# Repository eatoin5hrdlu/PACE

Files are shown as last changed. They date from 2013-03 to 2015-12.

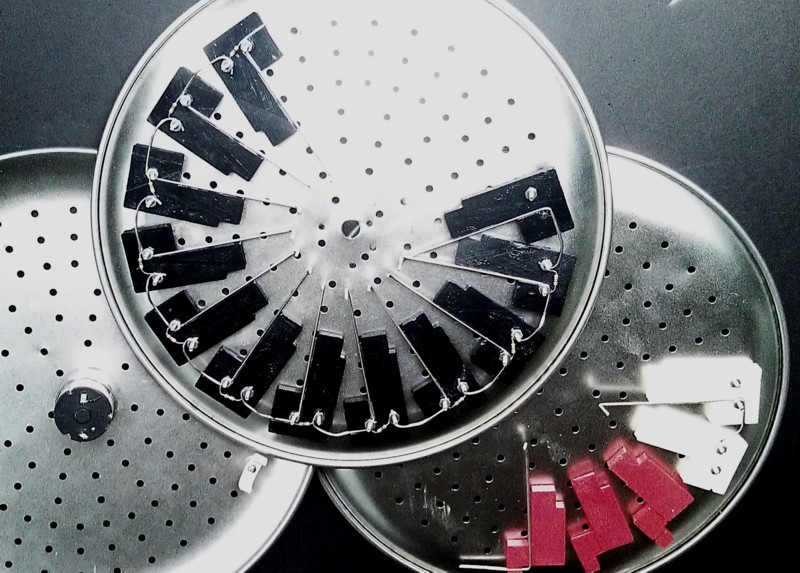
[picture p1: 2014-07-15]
CAD/assembly.jpg

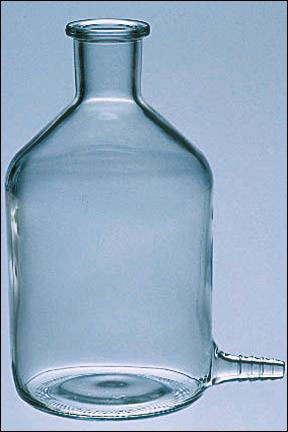
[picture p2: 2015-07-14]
Doc/F7747-01-wl.jpg

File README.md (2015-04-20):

EvoStat:  A PhageStat to support PACE and PATHE Experiments
NB: in the process of namechange from PACE to EvoStat. PACE github repository will disappear EvoStat will appear.
====
Software and Hardware for a low-cost platform for PACE and PATHE experiments.

PATHE (Phage-Assisted Three-Hybrid Evolution) is an enhancement to PACE (Phage Assisted Continuous Evolution) described by Kevin M. Esvelt, Jacob C. Carlson, and David R. Liu in http://www.ncbi.nlm.nih.gov/pubmed/21478873

This project contains Arduino code for a CellStat(Turbidostat), Sample Collector, and Lagoons
as well as the server software to provide an on-screen interface to Temperature, Turbidity, Flowrate,
and Sample Collector control and Web interface.

SWI-Prolog based web server, GUI, and Turbidostat control software
is written mostly in Prolog/Xpce with some Python (e.g. pySerial, for a 
portable serial interface to Arduino) and HTML. Bluetooth interface added as foreign function library to SWI-Prolog currently eliminates the need for pySerial. See github.com/eatoin5hrdlu/plblue 

Running EvoStat on a Linux or Windows machine provides an interface for multiple phageStats with using Bluetooth connected Arduino running host.ino for the Host Cellstat, multiple Bluetooth connected Arduinos for Lagoons (lagoon.ino), and a sample collector: Bluetooth connected Arduino running collector.ino. (Using a WiFi camera and bluetooth modules has reduced apparatus wiring by 90%)

It also contains a web server to provide essentially the same
interface via the URL:  

    http://&lt;machine-name&gt;:8080/evostat.pl    

Prerequisite Software
====
- Python2.7
- OpenCV (plus: "apt-get install python-opencv")
- SWI-Prolog with Xpce
- Arduino IDE (Processing)

Getting Started
====
Clone the repo:

    git clone https://github.com/eatoin5hrdlu/EvoStat.git

Run the app:

    cd app
    python levelapp.py

Using the controls, line up the lagoons and turbidostat in the camera frame
with the corresponding lines being  (blob detection being added to automate this)

Controls
====
* z  - read one frame and find levels and display
* r - read, find levels and display for 20 seconds.
* 0<nl>   Select the turbidostat as current vessel
* {1,2,3,4 for lagoons)
* <arrow keys> to move up/down/left/right, or:
* h  - move to the left
* j  - move down
* k  - move up
* l  - move right
* t -make region taller
* s - make region shorter
* f - make region fatter
* d - diminish (make region thinner)
* x - exits the program

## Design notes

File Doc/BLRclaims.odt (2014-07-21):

Title: A Laboratory Apparatus for Macromolecular and Biological Evolution

Inventor: Peter Reintjes

References:

Selection and Evolution of Bacteriophages in Cellstat, Yuruzu Husimi, Advances in Biophysics, Vol. 25, pp.1-43 (1989).

A system for the continuous directed evolution of biomolecules,Esvelt KM (http://www.ncbi.nlm.nih.gov/pubmed?term=Esvelt%20KM%5BAuthor%5D&cauthor=true&cauthor_uid=21478873)1, Carlson JC (http://www.ncbi.nlm.nih.gov/pubmed?term=Carlson%20JC%5BAuthor%5D&cauthor=true&cauthor_uid=21478873), Liu DR (http://www.ncbi.nlm.nih.gov/pubmed?term=Liu%20DR%5BAuthor%5D&cauthor=true&cauthor_uid=21478873), Nature. (http://www.ncbi.nlm.nih.gov/pubmed/21478873#) 2011 Apr 28;472(7344):499-503. doi: 10.1038/nature09929. Epub 2011 Apr 10.

pH Indicator, Wikipedia, http://en.wikipedia.org/wiki/PH_indicator

Background of the invention:

Macromolecular engineering can employ the mechanisms of evolution: mutation and selection, to construct novel genetic sequences with desired properties. Earlier means consisted of separate steps for mutation, selection, and cloning, with one or more manual steps, limiting the number of complete cycles to a few per day. Recent advances use continuous cell cultivation techniques, such as a cellstat, to create an environment for continuous evolution. One such method employs the evolution of a bacterial virus with a generation time on the order of a few minutes. A requirement for the application of these mechanisms is the relatively long-term maintenance of environmental conditions required by the organisms or macromolecules involved. Just as the simplest device to control a heating or cooling device from the feedback provided by a temperature sensor is called a thermostat, devices for controlling chemical concentrations, cell concentrations, and active bacterial virus populations are given the names chemostat, turbidostat, and phagestat. In each case, particular measurements correlated with the condition being maintained must be sensed to provide feedback for the control of temperature, nutrient concentration, flow rate, or other condition.

Sensors for some properties such as temperature, pH, reageant concentration may require contact with the materials involved and in the case of biological systems, this can require the devices to withstand an autoclaving procedure involving elevated temperature and pressures. In addition, such devices must withstand the potentially corrosive effects of the biological environment which can have chemistry similar to ocean water. For these reasons, we would prefer to use non-contact means (e.g optical) to measure environmental conditions.

Multiple light sources can be used with a single camera to detect the reflected color, degree of light scattering, and light absorption at various wavelengths. With the addition of chemical indicators such as pH indicators can allow the optical means to measure acidity and the addition of a sensitive infra-red detector to register accurate temperature measurements.

Substantial aeration may be necessary to achieve maximum growth rate of the host cell culture which can increase the acidity of the solution by the addition of dissolved carbon dioxide thereby requiring a means of controlling said acidity.

Summary of the invention:

A system of non-contact sensing means and computer activated controls to maintain multiple environmental conditions including, but not limited to, temperature, turbidity as a proxy for cell density, liquid levels, reflected or transmitted spectra as proxies for chemical concentrations and pH, biolumenescence as a proxy for phage population and macromolecule concentration.

Although mutation rates can be elevated and the selection process accelerated to the life-cycle of bacterial phage of only a few minutes, evolution experiments may still require days, weeks, or even longer to achieve the desired results. The present invention has increased reliability through the reduction of moving or wearing parts.

Precise pH stability is achieved by adding one or more non-toxic pH indicators to the nutrient stock which give a suitable color transition at the desired pH setting. A combination of reflected and absorbed spectral information can be used to gain precision.

A system necessary to maintain a stable population of bacterial phage (the evolving species), requires a cellstat subsystem to maintain the uninfected host cell production, which in turn requires turbidostat and thermostatic controls.

An indicator may be used to obtain quite precise measurements of pH by measuring absorbance at two or more wavelengths. The principle can be illustrated by taking the indicator to be a simple acid, HA, which dissociates into H+ and A-. HA is in equilibrium with H+ + A-

The value of the acid dissociation constant, pKa, must be known. The molar absorbances, εHA and εA- of the two species HA and A- at wavelengths λx and λy must also have been determined by previous experiment. Assuming that Beer's law is obeyed, the measured absorbances Ax and Ay at the two wavelengths are simply the sum of the absorbances due to each species.

A_x = [HA]\epsilon^x_{HA} + [A^-]\epsilon^x_{A^-}

A_y = [HA]\epsilon^y_{HA} + [A^-]\epsilon^y_{A^-}

These are two equation in the two concentrations [HA] and [A-]. Once solved, the pH is obtained as

\textrm{pH} = \textrm{pK}_{a}+ \log \frac{[\textrm{A}^-]}{[\textrm{HA}]}

If measurements are made at more than two wavelengths the concentrations [HA] and [A-] can be calculated by linear least squares. In fact a whole spectrum may be used for this purpose. The process is illustrated for the indicator bromocresol green. The observed spectrum (green) is the sum of the spectra of HA (gold) and of A- (blue), weighted for the concentration of the two species.

When a single indicator is used this method is limited to measurements in the pH range pKa ± 1, but this range can be extended by using mixtures of two or more indicators. Because indicators have intense absorption spectra the indicator concentration is relatively low so that it can usually be assumed that the indicator itself has negligible effect on pH.

Description of the drawings:

Drawing 1: Liquid flow path

1. Nutrient supply line
2. Nutrient supply pump
3. Nutrient supply valve
4. Host cell supply line
5. Host cell supply pump
6. Host cell supply valve
7. One-to-four line splitter for host cell supply
8. Host cell supply line for lagoon 1 (one of four)
9. Compression rod valve for Host cell supply for lagoon 1
10. Host cell supply canulla for lagoon 1
11. Inducer supply line
12. Inducer supply pump
13. Inducer supply valve
14. One-to-four line splitter for inducer
15. Inducer supply line for lagoon 1 (one of four)
16. Compression rod valve for inducer supply for lagoon 1
17. Inducer supply canulla for lagoon 1
18. Outflow canulla for lagoon 1 (one of four)
19. Compression rod valve for lagoon 1 outflow
20. Four-to-one line combiner
21. Outflow valve
22. Outflow pump

Drawing 2: Lighting and Image capture

1. Meniscus highlight LED for host cell incubator
2. Meniscus highlight LED for lagoon 1 (one of four)
3. LED Laser
4. Full spectrum LED
5. Camera

Chemostat

Turbidostat

Cellstat

Phagestat

Description of the invention:

A source of liquid nutrient sufficient to maintain the maximum flow rate through the system, a multiplicity of supplementary liquid reagents (inducers) which may be added to the containers.

A pump and valve complex, the primer, which can prime (valve closed, pump on) and then maintain (valve open, pump off) sufficient flow to sustain the maximum flow rate required by the system.

A flow control apparatus consisting of a multiplicity of valves controlling the flow of liquid between the outflow and inflow of the host cell container and each of the lagoons.

A host cell container which is elevated with respect to the phagestat containers (lagoons).

A multiplicity of secondary containers (lagoons) containing a population of bacteria and bacterial phage, each of said lagoons having one or more inputs from and one or more outputs to the flow-control apparatus.

A non-contact (IR) temperature sensor, camera, computer, and image processing software to provide real-time information about the level, turbidity, reflected color, spectral absorbance, and luminescence of the liquid in each of the transparent containers.

Means to control lighting in the form of yellow light projected up from beneath the transparent containers to illuminate the meniscus of the liquid in the container, a laser projecting into the transparent host cell container from the side, and a full spectrum light from the direction of the camera to provide visual monitoring of the apparatus.

A liquid sensing device in the bottom of the apparatus to detect leaks and a means to react to said leaks by shutting off the flow of liquid and a means for reporting the condition of the apparatus.

Claims:

Claim 1: Simultaneous liquid level detection for multiple transparent containers.

Consisting of an edge detection algorithm from the set {Marr-Hidreth, Roberts cross (http://homepages.inf.ed.ac.uk/rbf/HIPR2/roberts.htm), Sobel (http://homepages.inf.ed.ac.uk/rbf/HIPR2/sobel.htm), Compass (http://homepages.inf.ed.ac.uk/rbf/HIPR2/prewitt.htm), Canny (http://homepages.inf.ed.ac.uk/rbf/HIPR2/canny.htm)} followed by a line detection algorithm from the set {Hough, Convolution, (http://homepages.inf.ed.ac.uk/rbf/HIPR2/linedet.htm) Radon (http://en.wikipedia.org/wiki/Radon_transform) , Cauchy-Crofton (http://en.wikipedia.org/wiki/Crofton_formula) , Fourier (http://en.wikipedia.org/wiki/Fourier_transform) } to detect the illuminated meniscus of the liquid in said transparent containers.

Claim 2: Claim 1 where the transparent containers are illuminated from below.

Claim 3: Flow modulation consisting of multiple valves controlling a multiplicity of inputs and a single output for a multiplicity of containers where the amount of time alloted to opening each valve is varied to modulate the rate of flow through each valve.

Claim 4: The apparatus of claim 3 where the flow modulation for each container is a function of the instantaneous, time-derivative, and/or time-integral of the said containers liquid level.

Claim 5: The apparatus of claim 4 where the flow control parameters are computed by a calibration process consisting of:

1. An output leakage measurement taken by closing all input flow channels and measuring the rate of output flow with all output valves closed..
2. A nominal output flow measurement taken by closing all input flow channels and measuring the rate of output flow with each output valve opened for a specific interval.
3. An input leakage measurement consisting of closing of all output flow channels and measuring the rate of input flow with input valves closed.
4. A nominal input flow measurement taken by clsing all output flow channels and measuring the rate of input flow with each input valve opened for a specific interval.

Claim 6: The apparatus of claim 5 where the individual liquid containers are transparent and the rate of flow is measured by the image processing means of line detection.

Claim 7: The apparatus of claim 5 where the rate of flow is measured by detecting any or all of the instantaneous, time-derivative, and/or time-derivative liquid levels of the containers.

Claim 8: The apparatus of claim 5 where one or more pH indicators are added to the containers and a pH value is computed from the absorbence of wavelengths from one or more of the light sources.<

Keywords: multiple-valve, image processing, line detection, controlled illumination, turbidity.

Multi-valve control for liquid flow control of multiple

A Laboratory Apparatus for Macromolecular and Biological Evolution

10 Digital Outputs:

Laser

Yellow light

White light

Nutrient pump

Host cell pump and valve

Inducer pump and valve

Lagoon outflow pump and valve

1 PWM output: Valve pointer

1 Analog input

A system for controlling multiple turbidostats and cellstats with minimal medium contact.

Consisting of a dark environmental chamber with an optical (PIR, IR) temperature sensor, a heat source, a multiplicity of light sources under computer control, a digital camera connected to said computer, a multiplicity of liquid pumps, each with a valve whose input and output are in parallel with the pump input and output, an air pump, and stirring means in each of the containers.

A multiplicity of valves each consisting of a stiff rod compressing a soft tube in which the nutrient, cell culture, inducer, or other liquid would otherwise flow freely. A central pointer with adjustable torque which contacts said rods sequentially and flexes it sufficiently to relieve the compression on said tube allowing the liquid to flow freely for a specific time duration. At the end of said duration, the torque being increased to cause the pointer to push past the flexible rod, releasing it to allow it to recompress said tube, shutting off the liquid flow, whereupon the torque is immediately reduced to allow the pointer to come into light contact with the rod of the next valve. Said light contact being sufficient for the voltage present on said rod being conveyed to the pointer and then to the analog to digital converter of the computer, allowing the computer to detect the voltage and thereby identify the corresponding valve position of the central pointer.

Image event processing.

Image event processing eliminates the need to synchronize lighting changes with image processing.
, the main processor performs a quick analysis of the current image and performs

Yellow LED's lighting the containers from below indicates a level detection event,
Red laser light projecting a horizontal beam indicates a turbidity detection,
white light creates an image for User interregation, but also may indicate a
Phagestat operation implies a measurement of phage population density, which might be measured via bioluminescence when there is no external lighting. This algorithm requires the integration of many dark images, and so each image is analyzed to see that there is no external lighting before being incorporated into the signal integration data.

Other phage population density indicators may be used and may be detected from the white light image or integrated from multiple white-light images.

The image processing loop thus compiles the data for levels, turbidity, bioluminescence, and visible light color analysis depending upon the lighting detected in the image stream. The lighting control can be implemented by a simple mechanism which gives sufficient times to each of the required lighting conditions. During different phases of the experiment, more frequent turbidity or level measurements may be needed,


An important consequence of image event processing is that incorrect level or turbidity readings will never result from a researcher opening the capsule since that condition will be interpreted as a white-light event and simply update the web image picture. Previous turbidity or liquid levels will be considered valid until the correct image event (the correct lighting) is restored.

Images can be captured from any of a number of devices at various times and will be processed to update the monitored parameters according to the following image identification:

1. Fully illuminated image with full color spectrum and normal brightness: Update the human viewable “Web Image”.
2. Moderately illuminated image with predominantly yellow coloration: Identify liquid levels.
3. Low illumination image with predominantly red (laser) coloration: Use high contrast blob detection to evaluate turbidity.
4. Multiple point light source of different wavelengths behind the primary reactor vessel: Update absorbance data for wavelengths of each point source.
5. No detectable illumination: Add image information to integrated image for bioluminescence detection. For example, we add the value (+green – red/2 – blue/2) for each of 80 images to detect green bioluminescence.

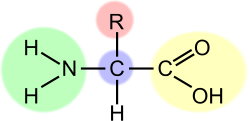
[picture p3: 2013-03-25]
open/images/genericAA.png

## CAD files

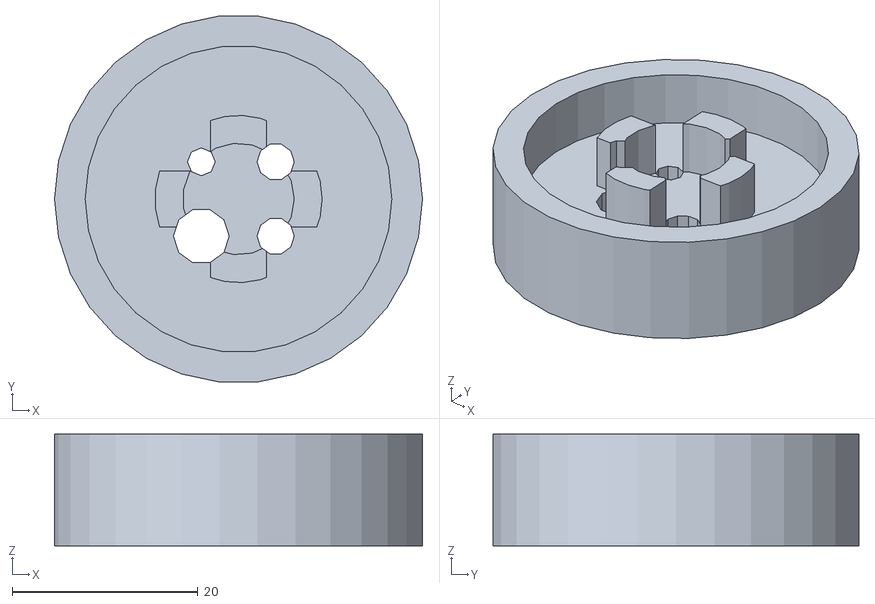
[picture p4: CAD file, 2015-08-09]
CAD/lagoon100cap.stl
39.6 x 39.4 x 12.0

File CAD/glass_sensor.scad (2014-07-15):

//
// Optical sensor to receive glass tube.
//
// dimensions subject to change, see variables
// at the bottom of this file
// 

module sensor()
{

  // Optical hole


	difference() {
	// BODY (to be subtracted from)
   cube([length,width,thick],center=true);

	// Glass Tube Conduit
	   rotate([0,90,0])
        cylinder(r=dia/2, h=lengthplus, center=true, $fn=smooth);
  // Slot
     translate([0,0.5+3*dia/2,0])
        cube([lengthplus,3*dia,dia+1],center=true);

  // Optical hole
     cylinder(r=lighthole, h=thickplus/2, center=true, $fn=smooth);

  // LED Holder
    translate([0,0,thick/2])
     cylinder(r=heatsinkradius, h=4, center=true, $fn=smooth);

    translate([0,0,thick/3])
     cylinder(r=ledradius, h=thick/4, center=true, $fn=smooth);

  // Phototransistor holder
    translate([0,0,2-thick/3])
     cylinder(r=phototransradius, h=1+thick/4, center=true, $fn=smooth);

// Phototansistor leads
     translate([1,0,-thick/2]) 
       cylinder(r=0.5, h=thickplus/2, center=false, $fn=smooth);
     translate([-1,0,-thick/2]) 
       cylinder(r=0.5, h=thickplus/2, center=false, $fn=smooth);

  } // end difference

  smooth = 8;  // Number of facets for round features
	length = 80; // mm   (76mm = 3") Main Block
	width  = 30; // mm
	thick = 20;  // mm
   dia  = 6.4;  // 1/4 inch in mm
  heatsinkradius = 25.4*(7/16);
  ledradius = 3;
  phototransradius = 2.1;
	thickplus = thick + 2;  // plus margin
  lengthplus = length + 2;

}

rotate([90,0,0]) sensor();

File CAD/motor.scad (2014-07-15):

module mount(inner, length) {
side = (inner+6)/3;

	difference() {
     union() {
		cylinder(r=inner+4, h=length, center=true);
	    translate([0,0,-length/3])
		cylinder(r=inner+8, h=length/4, center=true);
      }
		cylinder(r=inner, h=length+2, center=true);

	    translate([inner,-3,6.2])  // X
			cube([side,2*side,length-2], center=true);

	    translate([-inner,-3,6.2])  // -X
			cube([side,2*side,length-2], center=true);

	    translate([0,inner,6.2])     // Y
			cube([side,2*side,length-2], center=true);

	    translate([0,-inner,6.2])  // -Y
			cube([side,2*side,length-2], center=true);

    }
}

module hole(x,y,radius) {
	translate([x,y,0])
	cylinder(r=radius,h=48,center=true);
}

module base(outer, inner, height) {
	difference() {
	  cylinder(r=outer, h=height, center=true);
	  cylinder(r=inner, h=height+2, center=true);
    }
}



// motor_radius = 18.5;
motor_radius = 18.5;
long = 25;
shaft = 6.5;
motor_offset = 7;
offset = 18.5;

difference() {
 union() {
  base(1.8*motor_radius, shaft, 6);
  translate([0,motor_offset,long/2])
	  mount(motor_radius, long);

  }
  translate([0,motor_offset,0])
	  cylinder(r=13.4,h=10,center=true);
	hole(offset,0,2.7);
	//  hole(0, offset, 1);
	hole(-offset,0,2.7);
	hole(0,-offset,2.7);
 }

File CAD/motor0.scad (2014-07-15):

module mount(outer, length) {
	difference() {
     union() {
		cylinder(r=outer, h=length, center=true);
	    translate([0,0,-length/3])
		cylinder(r=outer+6, h=length/4, center=true);
      }
		cylinder(r=outer-3, h=length+2, center=true);
	    translate([outer-3,0,0])  // X
			cube([outer/3,outer/3,length+2], center=true);

	    translate([-(outer-3),0,0])  // -X
			cube([outer/3,outer/3,length+2], center=true);

	    translate([0,outer-3,0])     // Y
			cube([outer/3,outer/3,length+2], center=true);

	    translate([0,-(outer-3),0])  // -Y
			cube([outer/3,outer/3,length+2], center=true);

    }
}

module hole(x,y,radius) {
	translate([x,y,0])
	cylinder(r=radius,h=24,center=true);
}

module base(outer, inner, height) {
	difference() {
	  cylinder(r=outer, h=height, center=true);
	  cylinder(r=inner, h=height, center=true);
    }
}



motor_radius = 18.5;
long = 25;
shaft = 6;
motor_offset = 7;
offset = 18.5;

difference() {
 union() {
  base(1.7*motor_radius, shaft, 5);
  translate([0,motor_offset,long/2])
	  mount(motor_radius, long);
  }
	hole(offset,0,1.7);
	//  hole(0, offset, 1);
	hole(-offset,0,1.7);
	hole(0,-offset,1.7);
 }

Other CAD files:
CAD/samplemotor.scad
CAD/black4bevel.scad
CAD/cellstat.scad
CAD/cellstatcap.scad
CAD/cellstatcaplogo.scad
CAD/collar.scad
CAD/innatrix_logo.scad
CAD/lagoon100cap.scad
CAD/lagoon250cap.scad
CAD/newsample.scad
CAD/nystop.scad
CAD/optical2.scad
CAD/pacezeroskp.skp
CAD/pointer.scad
CAD/rotary.scad
CAD/rotary100.scad
CAD/rotarylong.scad
CAD/rotarynut.scad
CAD/rotaryss.scad
CAD/rotaryssp4post.scad
CAD/smalllogocap.scad
CAD/spair.scad
CAD/stopper.scad
CAD/turbidostat.scad
CAD/turbidostatbar.scad
CAD/turbine.scad
CAD/turbo.scad

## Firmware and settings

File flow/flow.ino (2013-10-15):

/*
 * Flow controller normal operation:
 *
 * Turn pumps on/off for a few seconds every minute to approximate
 * optimal flow rate (2.5 vol/hour, vol = 200mL)
 *
 * Commands:
 *  {id}{io}N : Increase/decrease input/output flow for lagoon N
 *      Add or subtract an increment to on time of the specified pump.
 *
 *  ci : Calibrate In-flow, increase working level:
 *      Disable all out-flow pumps
 *      Run three cycles of all Input pumps (off time equal to on time)
 *      Sleep for 10 seconds
 *      Re-enable normal pump cycle.
 *
 *  co : Calibrate Out-flow, decrease working level:
 *      Disable all in-flow pumps
 *      Run three cycles of all Output pumps (off time equal to on time)
 *      Sleep for 10 seconds
 *      Re-enable normal pump cycle.
 *
 */

//#define DEBUG 1
#define STANDALONE 1

/* CONSTANTS AND GLOBAL VARIABLES */

#define PUMP_CYCLE	30000 // mSec between pumping cycles
#define PUMP_ORIGIN	2     // First pin for eight lagoon pumps
#define LAST_PUMP	9
#define TURBID_LED	10    // Turbidity LED is a PWM pin
#define HEATER		11    // Power for heater
#define VALVE		12
#define LED		13

#define TURBIDITY	0    // Analog pins
#define TEMPERATURE	1

#define IN		0     // Pin # offset for input
#define OUT		4     // and output pumps

boolean auto_temp;  // Automatically control Heater
boolean auto_flow;  // Maintain Flow Control
boolean auto_valve; // Use Valve to maintain turbidity

int interval;   // Variable to keep track of the time
int reading[10];

// Store the on-time, for each of the four input and four
// output pumps.  These values (in milliSeconds) will be
// updated with optimal values that will be stored in EEPROM.

int   rate[8]	=	{	3000, 3000, 3000, 3000,
				3000, 3000, 3000, 3000 };

int cycle = IN;      // State variable for which cycle (IN/OUT) we are in
int cntr = 1;        // Loop iteration counter
long unsigned int start_time = 0;  // When pumps were last turned on

byte cal;	// Calibration constant (LED current)
byte temp;      // Thermostat setting

#define CLEAR	200.0   // Constant for clear water OD

int turbid  = 	500;    // Constant for optimal OD

/* TEMPERATURE CONTROL */

void temp_setup()
{
	auto_temp = true;
}

void check_temp()
{
	int t = get_average(TEMPERATURE);
	if ( t < temp )
		digitalWrite(HEATER,1);
	else
		digitalWrite(HEATER,0);
}

/* ROLLING AVERAGE OF OPTICAL DENSITY READINGS */

int  ai;	
int rollval[10]	= {	200, 200, 200, 200, 200,
			200, 200, 200, 200, 200, };

int add2rollingavg(int n)
{
int sum = 0;
	rollval[ai] = n;
	ai = (ai + 1)%10;
	for (int i=0;i<10;i++) sum += rollval[i];
	return sum/10;
}
	
void showpumps(void)
{
	for (int i=0; i<8; i++)
	{
		Serial.print(digitalRead(PUMP_ORIGIN+i));
		Serial.print("   ");
	}
	Serial.println("");
}

/* EEPROM SAVE AND RESTORE OF ID AND CALIBRATION CONSTANTS */

#ifdef STANDALONE
#include "EEPROM.h"
#define SAVE	1
#define RESTORE	0
int RomAddress  = 0;
byte id = 'z'; // Zeno = unassigned, by default

// 'RomAddress' global will be bumped by successive
// calls to moveData( SAVE|RESTORE, size, ptr)

void moveData(int op, int size, byte *loc)
{
	for(int i=size;i>0;i--)
		if (op == SAVE)
			EEPROM.write(RomAddress++,*loc++);
		else
			*loc++ = EEPROM.read(RomAddress++);
}

void saveRestore(int op)
{
	RomAddress = 0;
	moveData(op, 1, &id);
	for(int i=0;i<8;i++) moveData(op, sizeof(int), (byte *)(&rate[i])  );

	moveData(op, 1, &cal);

	moveData(op, 1, &temp);

	moveData(op, sizeof(int), (byte *)&turbid);
}
#endif

void printHelp(void)
{
	Serial.print("\n\n");
	Serial.println("a : set auto {temp, flow, valve} mode");
	Serial.println("at: set auto heater mode");
	Serial.println("af: set auto pump mode");
	Serial.println("av: set auto valve mode");
	Serial.println("iX : Set ID to X");
	Serial.println("m : set manual {temp, flow, valve} mode");
	Serial.println("mt: set manual heater mode");
	Serial.println("mf: set manual pump mode");
	Serial.println("mv: set manual valve mode");

	Serial.println("p+N: turn pump N on");
	Serial.println("p-N: turn pump N off");

	Serial.println("iiN: Increase input flow for Lagoon N");
	Serial.println("ioN: Increase output flow for Lagoon N");
	Serial.println("diN: Decrease input flow for Lagoon N");
	Serial.println("doN: Decrease output flow for Lagoon N");
	Serial.println("fi : Measure in-flow rate");
	Serial.println("fo : Measure out-flow rate");
	Serial.println("w : calibrate at 200 (e.g. clear water)");
	Serial.print("l : calibrate at "); Serial.println(turbid);
}

boolean flow_command(char c1, char c2, int value)
{
	int direction;
	if (c2 == 0) // SINGLE LETTER COMMANDS
	{
		switch(c1)
		{
			case 'a':
				auto_temp = true;
				auto_flow = true;
				auto_valve = true;
				break;
			case 'c':
				Serial.println(cal);
				break;
			case 'i':
				Serial.write(id);
				Serial.println();
				break;
			case 'l':
				calibrateLED(turbid);
				analogWrite(TURBID_LED, cal);
				break;
			case 'm':
				auto_temp = false;
				auto_flow = false;
				auto_valve = false;
				break;
			case 'o':
				Serial.println(get_average(TURBIDITY));
				break;
			case 't':
				Serial.println(temp);
				break;
			case 'w':
				calibrateLED(CLEAR);
				analogWrite(TURBID_LED, cal);
				break;
			default:
				return false;
		}
		return true;
	}
	switch(c2) 
	{
		case 'i': direction = IN;   break;
		case 'o': direction = OUT;  break;
		default:  id = c2;
	}
	switch(c1)
	{
		case 'a':
			switch(c2)
			{
			case 'v': auto_valve = true; break;
			case 't': auto_temp = true; break;
			case 'f': auto_flow = true; break;
			}
			return true;
		case 'd':	rate[direction+(value-1)] -= 1000;
				saveRestore(SAVE);
				break;

		case 'f':	force_flow(direction);
				break;

		case 'h':
			if (auto_temp) return true;
			switch(c2)
			{
			case '+': digitalWrite(HEATER,1); break;
			case '-': digitalWrite(HEATER,0); break;
			default: return false;
			}
			break;
		case 'i':	id = c2;
				saveRestore(SAVE);
				break;
		case 'm':
			switch(c2)
			{
			case 'v': auto_valve = false; break;
			case 't': auto_temp = false; break;
			case 'f': auto_flow = false; break;
			}
			return true;
		case 'p':
			if (auto_flow) return true;
			switch(c2)
			{
			case '+':
				digitalWrite(PUMP_ORIGIN+(value-1), 1);
				break;
			case '-':
				digitalWrite(PUMP_ORIGIN+(value-1), 0);
				break;
			default :
				return false;
			}

		case 'u':	rate[direction+(value-1)] += 1000;
				saveRestore(SAVE);
				break;
		case 'v':
			if (auto_valve) return true;
			switch(c2)
			{
			case 'o': digitalWrite(VALVE,1); break;
			case 'c': digitalWrite(VALVE,0); break;
			default: return false;
			}
			break;

		default:
			return false;
	}
	return true;
}

void respondToRequest(void)
{
	String is = "";
	while (Serial.available() > 0)  // Read a line of input
	{
		int c  = Serial.read();
		if ( c < 32 ) break;
		is += (char)c;
		if (Serial.available() == 0) // It is possible we're too fast
			delay(100);
	}
	if ( is.length() > 0 )  {   // process the command
		int value = 0;
		if (is.length() > 2)
			value = atoi(&is[2]);
		if (!flow_command(is[0], is[1], value))
			Serial.println("bad flow command [" + is + "]");
	}
}

/*
 * average() throw out two extreme values and average the rest
 */

float average(int *arr, int size)
{
	float avg = 0;
	int mx = 0;
        int mn = 2000;
	for (int i=0; i<size; i++) 
	{
		avg += arr[i];
		if (arr[i] < mn) mn = arr[i];
		if (arr[i] > mx) mx = arr[i];
	}
	return ( ( avg - (mn+mx) )/(size-2));
}

float stdev(int *arr, int size, float avg)
{
	float sumsq = 0;
	int mx = 0;
        int mn = 2000;
	for (int i=0; i<size; i++)
	{
		sumsq += (avg - arr[i])*(avg - arr[i]);
		if (arr[i] < mn) mn = arr[i];
		if (arr[i] > mx) mx = arr[i];
	}
	sumsq = sumsq - (avg - mn)*(avg - mn);
	sumsq = sumsq - (avg - mx)*(avg - mx);
	return sqrt(sumsq/(size-2));
}

/*
 * Return average of 10 readings of analog input
 */

float get_average(int Ain)
{
	for (int j=0; j<10; j++) {
		delay(10);
		reading[j] = analogRead(Ain);
	}
	return average(reading, 10);
}


/* PUMP CONTROL
 *
 * check_pumps() takes the time the pumps were last started
 * and returns the same value until the pumps are all shut off,
 * when it will return 0.
 */

int check_pumps(int started)
{
	int elapsed = millis() - started;
	for (int i = 0; i < 8; i++)
	{
		if (elapsed > rate[i] && digitalRead(PUMP_ORIGIN+i) == 1)
		{
			digitalWrite(PUMP_ORIGIN+i,0);
			int tm_err = (elapsed - rate[i])-1;
			if (tm_err > 2) {
#ifdef DEBUG
				Serial.print(i);
				Serial.print(" pump off error: ");
				Serial.println((elapsed - rate[i])-1);
#endif
			}
		}
	}
	if (pumps_on()) return started;
#ifdef DEBUG
	else		Serial.println("no pumps on");
#endif
	return 0;
}

boolean pumps_on(void)     /* Are any pumps on? */
{
	for (int i = 0; i < 8; i++)
		if ( digitalRead( PUMP_ORIGIN + i ) == 1)
			return true;
	return false;
}

int start_pumps(int direction)
{
#ifdef DEBUG
	if (pumps_on()) Serial.println("Pumps were already on!");
#endif
	int start = PUMP_ORIGIN + direction;
	int stop = start + 4;
	for (int i = start; i < stop; i++) digitalWrite(i,1);
	return millis();
}
	

void force_flow(int direction)
{
	int off_pumps;
	if (direction == IN)	off_pumps = OUT;
	else			off_pumps = IN;
	for(int i=0; i<4; i++ )
		digitalWrite(PUMP_ORIGIN+off_pumps+i,0);

	for(int t=0; t<3; t++)          // Three cycles
	{
		for(int i=0; i<4; i++ ) // For each pump
		{
			digitalWrite(PUMP_ORIGIN+direction+i,1);
#ifdef DEBUG
			Serial.print("Pump ");
			Serial.print(direction+i+1);
			Serial.println(" on");
#endif
			delay(rate[direction+i]);
			digitalWrite(PUMP_ORIGIN+direction+i,0);
#ifdef DEBUG
			Serial.print("Pump ");
			Serial.print(direction+i+1);
			Serial.println(" off");
#endif
			delay(1000);
		}
	}
	interval = 1 + (millis()/PUMP_CYCLE); // Restart pumping after delay
}



void flow_setup()
{
	auto_flow = true;  // Maintain Flow Control
	pinMode(HEATER, OUTPUT); // up to 7KW heater
	pinMode(VALVE, OUTPUT);	 // Bacterial Nutrient supply valve
	pinMode(LED, OUTPUT);	 // Arduino Indicator light
	interval = millis()/PUMP_CYCLE; // Intervals since startup (zero?)
	for (int i=0;i<8;i++) {
		pinMode(PUMP_ORIGIN+i, OUTPUT);
		digitalWrite(PUMP_ORIGIN+i, 0);
	}
#ifdef DEBUG
	Serial.print("Pumps initially set to: ");
	showpumps();
	Serial.print("On-times initially set to: ");
	for(int i=0;i<8;i++) { Serial.print(rate[i]);Serial.print("   "); }
	Serial.println("");
#endif
}


void check_flow()
{
#ifdef DEBUG
	if (cntr%(PUMP_CYCLE/30)==0)	showpumps();
#endif
	// Don't bother to check pumps if start_time is zero
	// (e.g. Last we checked, all pumps were off)

	if (start_time > 0)
		start_time = check_pumps(start_time);
	int current = millis() / PUMP_CYCLE;

	if ( current > interval )  // Time for a pumping cycle
	{
#ifdef DEBUG
		Serial.println("pump cycle");
#endif
		interval = current;
		start_time = start_pumps(cycle);
		if (cycle == IN) cycle = OUT;
		else             cycle = IN;
#ifdef DEBUG
		showpumps();
#endif
	}
	cntr++;
}

/* OPTICS FOR TURBIDITY MEASUREMENT */

void turbid_setup()
{
	auto_valve = true;  // Maintain turbidity with medium flow
	ai = 0; // Initialize index for rolling average array
	analogWrite(TURBID_LED, cal);
}

void check_turbid()
{
	if (get_average(TURBIDITY) > turbid)
		digitalWrite(VALVE, 1);
	else
		digitalWrite(VALVE, 0);
}

int LEDcalibration(int nominal)
{
int	ledout = 128;
int	change = ledout/2;
	analogWrite(TURBID_LED, ledout);
	delay(200);
float	avg = get_average(TURBIDITY);
int 	error = (int) (avg - (float)nominal);

	while ( abs(error) > 2)
	{
		if (error < 0) ledout = ledout - change;
		else           ledout = ledout + change;
		change = change/2 + 1;
		analogWrite(TURBID_LED, ledout);
		delay(200);
		avg = get_average(TURBIDITY);
		error = (int) (avg - (float) nominal);
	}
	return ledout;
}

/*
 * Find the LED current (PWM output) corresponding
 * to the specified sensor output.
 */

void calibrateLED(int level)
{
int tmp;
int avg = 0;

#ifdef DEBUG
	Serial.println("wait 5 seconds");
	delay(5000);
#endif
	for(int i=0; i<10; i++)
	{
		delay(300);
		tmp = LEDcalibration(level);
#ifdef DEBUG
		Serial.println(tmp);
#endif
		avg += tmp;
	}
	avg = (int) ((float)avg) / 10.0;
#ifdef DEBUG
	Serial.print(avg);
	Serial.print("  /10 ->  ");
	Serial.println(avg);
#endif
	cal = (byte) avg;
	saveRestore(SAVE);
}


/*
 * setup()	1) Initializes serial link
 *		2) Restores settings from EEPROM
 *		2) Calls flow_setup (pumps)
 *		3) Calls turbid_setup (LED/Optics)
 */

void setup()
{
	Serial.begin(9600);	// 9600 baud, 8-bits, no parity, one stop bit
	if (EEPROM.read(0)==0)	// First time
	{
		id = 'a';	// Default ID 'Aristotle'
		cal = 141;	// Default LED current/light level
		temp = 100;	// Temperature set point
		turbid = 500;	// Turbidity set point
		saveRestore(SAVE);
	}
	else
		saveRestore(RESTORE);

	temp_setup();
	flow_setup();
	turbid_setup();
}

void loop() 
{
	delay(2);		// Delay between reads for stability
	respondToRequest();	// Handle query from user/computer

	if (auto_flow)		// Check and update pumps
		check_flow();

	if (auto_temp)		// Check and update heater
		check_temp();

	if (auto_valve)		// Check and update valve
		check_turbid();

}

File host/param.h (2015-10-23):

#define STANDALONE 1

#define SAVE	1          // EEPROM STORAGE COMMANDS
#define RESTORE	0

#define ANALOG_TEMPERATURE   0 // Analog input for temperature
#define ANALOG_LEAK          1 // Analog input for leak detection
#define ANALOG_TURBIDITY     3 // Analog input for turbidity

#define AIR            10     // Control solid-state relay (~120VAC)
#define HEATER          9     // Control solid-state relay (~40VAC)
#define LED             13     // Turbidity light
#define LASER           8     // Meniscus light
#define JARLIGHT        7     // Meniscus light
#define NUTRIENT        4     // Only one valve for Cellstat
#define HOSTOUT         5     // Output to Waste
#define MIXER           3     // PWM for 12V motor

#define DEFAULT_CYCLETIME       20  // Seconds

#define NUM_VALVES      2
#define MAX_VALVES      6

#define MIXERSPEED 110   // PWM value for top mixer speed

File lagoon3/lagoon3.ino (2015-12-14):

/*
 * Lagoon controller
 *
 * 1) Create valve controller
 * 2) Accept commands from main computer to:
 *     a) adjust timings
 *     b) control meniscus light
 *     c) set auto/manual temperature control
 *     d) set auto/manual flow control
 * 3) Check temperature and manage lagoon heater
 */
#include "param.h"

#include <Servo.h>
Servo myservo;

int calibration;

void swrite(int val) {
     if (calibration != 2) {  // Do not enable(LOW) when calibrating outflow
	digitalWrite(VALVEENABLE,0);
	delay(150);
     }
     myservo.write(val);
     delay(150);
     digitalWrite(VALVEENABLE,1);
}

#include "valve.h"        // Includes param.h (change constants there)
VALVE    valve = VALVE(NUM_VALVES+1, VALVEPIN);      // 5-position valve on pin 9


#include "temperature.h" 
TEMPERATURE temp = TEMPERATURE(0);  // Analog Temperature on pin A0

boolean auto_temp;   // Automatically control Heater
boolean auto_valve;  // Automatically control Valves
boolean auto_mixer;  // Automatically cycle mixer

/* EEPROM SAVE AND RESTORE OF ID AND CALIBRATION CONSTANTS */

#ifdef STANDALONE
#include "EEPROM.h"
int RomAddress  = 0;

int mixerspeed;
byte id = 'z'; // Zeno = unassigned, by default
float target_temperature;

int interval;   // Variable to keep track of the time
int reading[10];

// Keep temperature within 0.5 degree C

void checkTemperature()
{
float t = temp.celcius();
	if (t < target_temperature)        digitalWrite(HEATER,1);
	if (t > target_temperature + 0.5)  digitalWrite(HEATER,0);
}

// 'RomAddress' global will be bumped by successive
// calls to moveData( SAVE|RESTORE, size, ptr)

void moveData(int op, int size, byte *loc)
{
	for(int i=size;i>0;i--)
		if (op == SAVE)
			EEPROM.write(RomAddress++,*loc++);
		else
			*loc++ = EEPROM.read(RomAddress++);
}

char *saveRestore(int op)
{
	RomAddress = 0;
	moveData(op, 1, &id);
	moveData(op, sizeof(float),      (byte *) &target_temperature);
	moveData(op, sizeof(int),        (byte *) &mixerspeed);
	moveData(op, sizeof(int),                valve.getOutflowms());
	moveData(op, (NUM_VALVES+1)*sizeof(int), valve.getTimes());
	moveData(op, (NUM_VALVES+1)*sizeof(byte),valve.getAngles());
	if (op == SAVE) return("save.");
	else            return("restore.");
}
#endif

/* Commands:
 *  a0 :    Auto modes off
 *  a1 :    Auto modes on
 *  cN :    Calibration modes (0,1,2)
 *  dNaa :  Set angle for valve position N
 *   EXAMPLE  Set angle for 0th valve position at 10 degrees (rather than 0)    "d010"
 *   EXAMPLE  Set angle for 4th valve position at 178 degrees (rather than 180) "d4178"
 *  h0 :    Heater off
 *  h1 :    Heater on
 *  l0 :    Meniscus light off
 *  l1 :    Meniscus light on
 *  m0 :    Mixing motor off
 *  m1 :    Mixing motor on
 *  ph :    Print Help (this list of commands)    
 *  pN :    Go to Valve position N, auto_valve mode off
 *  r  :    Restore settings from EEPROM
 *  tNNNN:  Set target temperature in tenths of degrees  371 = 37.1C
 *  t  :    Get current temperature
 *
 *  n  : Normal (run mode) : calibration off, auto modes on
 */

void printHelp(void)
{
	Serial.println("cmd(a,[0,1],'set auto modes off/on').");
	Serial.println("cmd(c,[0,1,2],'Calibrate modes(0=normal,1=inflow,2=outflow').");
	Serial.println("cmd(d,[0,1,2,3,4],[45,90,135,180],'set angle:(0-180) for Nth valve position').");
	Serial.println("cmd(h,[0,1],'heater off/on auto_temp off').");
	Serial.println("cmd(l,[0,1],'light off/on').");
	Serial.println("cmd(m,[0,1],'mixer off/on').");
	Serial.println("cmd(n,'Normal Run mode (valve enabled, valve pos 0, auto_modes on)').");
	Serial.println("cmd(p,[1],[0,1,2,3,4],'set valve to position N, auto_valve off').");
	Serial.println("cmd(r,'Restore settings from EEPROM').");
	Serial.println("cmd(s,'Save settings in EEPROM').");
	Serial.println("cmd(t,[371],'Set target temperature in tenth degrees:37.1C').");
	Serial.println("cmd(t,'Get temperature').");
}

void mixer(byte v)
{
	if (v == 0)
		analogWrite(MIXER,0);
	else 
	    for(int i=3; i<11; i++) {
		analogWrite(MIXER, i*mixerspeed/10);
		if (auto_valve) valve.checkValve();
		delay(400);
 	    }
}

boolean lagoon_command(char c1, char c2, int value)
{
char reply[80];
byte d;
int tmp;
     reply[0] = 0;  
	switch(c2)
	{
		case '1': d = 1; break;
		case '0': d = 0; break;
		default : break;
	}
	switch(c1)
	{
		case 'a':
			if (d == 1) {
				auto_temp = true;
				auto_valve = true;
				auto_mixer = true;
			} else {
				auto_temp = false;
				auto_valve = false;
				auto_mixer = false;
			}
			break;
		case 'c':
		        calibration = c2 - '0';
			auto_temp = false;
			auto_valve = false;
			valve.enable(1);
			valve.position(0);
			valve.calibrate(calibration);
			break;
		case 'd':
		        valve.setAngle(c2,value);
			break;
		case 'e':
			valve.enable(d);
			break;
		case 'h':
			digitalWrite(HEATER, d);
			break;
		case 'i':
			if (c2 != 0)
				id = c2;
			else {
				Serial.print("id(");
				Serial.print(id);
				Serial.println(").");
			}
			break;
		case 'l':
	                if (d == 1)
				digitalWrite(LED, 1);
			else
				digitalWrite(LED, 0);
			break;
		case 'm':
			Serial.print("mixer(");
			Serial.print(d);
			Serial.println(").");
			Serial.println(d);
			mixer(d);
			break;
		case 'n':
		        calibration = 0;
			valve.calibrate(0);
			valve.enable(1);
			valve.position(0);
			auto_temp = true;  // Maintain Temperature Control
			auto_valve = true;  // Maintain Flow
			break;
		case 'o':
		        if (c2 == 'f') valve.setOutflowms(value);
			else           return false;
			break;
		case 'p':
		        if (c2 == 'h') printHelp();
			else {
			     auto_valve = false;
			     valve.position(c2-'0');
			}
			break;
		case 'r':  
			switch(c2) {
				case 'v': valve.report(reply);
				     	  break;
				case 't':
					Serial.print("temperature(");
					Serial.print(temp.celcius());
					Serial.println(").");
					break;
				default: strcpy(reply,saveRestore(RESTORE));
					 break;
			}
			break;
		case 's':
			strcpy(reply,saveRestore(SAVE));
			break;
		case 't': // set target(ts), get target(tt) or get current temp (t)
		        if (c2 == 's')
			   target_temperature = ((float)value)/10.0;
		        else {
			     if (c2 == 't') {
			     	    tmp = (int) (target_temperature*10.0);
				    Serial.print("target_");
			     }
			     else
				tmp = (int) (temp.celcius()*10.0);
			     Serial.print("temperature(");
			     Serial.print(tmp);
			     Serial.println(").");
			}
			break;
		case 'v':
			valve.setup_valve(c2-'0', value);
			break;
		default:
			return false;
	}
	if (strlen(reply) > 0) Serial.println(reply);
	Serial.println("end_of_data.");	
	return true;
}
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

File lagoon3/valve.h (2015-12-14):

#ifndef VALVE_v1_h
#define VALVE_v1_h
#define LIBRARY_VERSION	1.0.0
// FROM LAGOON2
// The number of valves and initial timings are specified in
// the constructor, rather than having a parameterized object.
//
// METHODS:
//
// void position( valve ) - Go to this position
// int getTime( valve )     - Return the valves "open time" value
// int setTime(int v, int t)- Set valves "open time" value
// void adjust(valve, value)- Add value to the valve's current "open time"
// boolean checkValve()    - Open valves if time for a new cycle and
//                            close valves after their "open time" 
// void openValve(int v)    - Open the valve for its "open time" duration
//
#include "Arduino.h"
//#include "param.h"

class VALVE
{
 public:
  VALVE(int n, int pin) {
    int i;
    size = n;
    disabled = false;
    //  Angles are stored in EEPROM and can now be changed and remembered
    //    for(i=0;i<size;i++)   {
    //      int angle = i*(180/(size-1));  // Angles are 0, 45, 90, 135, 180
    //      valve_angle[i] =  angle;
    //    }
    cycletime = DEFAULT_CYCLETIME*1000; // Cycle in seconds, store as ms
    lastcycle = millis();
  }

  void enable(int d)
  {
    if (d) disabled = false;
    else   disabled = true;
    swrite(valve_angle[0]);
    current = 0;
  }

  void position(int v) {
    swrite(valve_angle[v]);
  }

  void set_drain_pin(int p) {
    drain_pin = p;
  }

  void setup_valve(int v, int tm) {
    valve_open[v] = 0;
    if (v == size-1)
      valve_time[v] = tm;
    else
      valve_time[v] = tm/2;
  }

  int getSize(void)           { return size;  }
  int getCycletime(void)      { return cycletime/1000;  }
  void setCycletime(int secs) { cycletime = secs*1000; }

  // report() takes a pointer to a buffer 
   void report(char *reply) {
     char *cp = reply;
     sprintf(cp,"valvetimes([");
     cp += 12;
     for(int i=0; i<size; i++) {
	 sprintf(cp, "%5d,",valve_time[i]);
	 cp += 6;
     }
     sprintf(cp-1,"]).");
   }

   void next_valve(void)
   {
    if (current == 0)            up = true;  // First half of sequence
    if (up && current == size-1) up = false; // Second half
    valve_open[current] = 0;
    if (up) current = current + 1;
    else    current = current - 1;
    swrite(valve_angle[current]);
    if (current != 0)
      valve_open[current] = millis();
   }

boolean checkValve(void) {
  int i;
  unsigned long now = millis();

  if (disabled)
    return false;
  
   if ((outflowon+outflowms) < now )
     {
       digitalWrite(outflowPin,0);  // OUTFLOW OFF AT END OF outflowms
       outflowon = 0;
     }

  if (current != 0 &&  (now > valve_open[current] + valve_time[current]) )
    next_valve();
  
  if (now > lastcycle + cycletime) // Time to start valve sequence
    {
      lastcycle = millis();
      current = 0;
      next_valve();
      if (calibration != 1) {
	digitalWrite(outflowPin,1);        // OUTFLOW ON AT START OF CYCLE
	outflowon = millis();
      }
    }
  return true;
}

  byte *getTimes()              { return (byte *)&valve_time[0];       }
  int getTime(int vchar)        { return valve_time[(int)(vchar-'0')]; }
  int setTime(char vchar, int t){ valve_time[(int)(vchar-'0')] = t; }

  byte *getAngles()              { return &valve_angle[0];   }
  int setAngle(char vchar, int a){ valve_angle[(int)(vchar-'0')] = a; }
  int setOutflowms(int outms)   { outflowms = outms; }
  int setOutflowpin(int p)      { outflowPin = p; }

  byte *getOutflowms()          { return (byte *)&outflowms; }
  void calibrate(int c)         { calibration = c; }

 private:
  int size;                         // Number of positions
  int current;                      // Current position
  int calibration;                  // Calibration Mode 1=inflow, 2=outflow
  boolean up;
  boolean disabled;
  byte     flow;
  int      valve_time[NUM_VALVES+1];
  byte     valve_angle[NUM_VALVES+1];
  long int valve_open[NUM_VALVES+1];  // When was the valve opened

  unsigned long lastcycle;  // Beginning of current time interval
  unsigned long cycletime; // Cycle duration (always > valve on time)
  unsigned long outflowon;
  int outflowms;
  int outflowPin;
 } ;
#endif

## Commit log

2013-03-25 Added Arduino code for Turbidostat microcontrollers
2013-03-26 Timer repeats data collection and file creation
2013-04-07 sample data file for initial testing
2013-04-18 Added Sample Collector Arduino code
2013-05-01 Moved Arduino code into self-named directories
2013-10-15 Added newest Arduino code
2014-07-14 PID control, new interface on main PACE GUI
2014-07-15 3D Printer CAD files
    [black4bevel.scad, collar.scad, glass_sensor.scad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]
2014-07-15 removed all generated files
    [turbine_housing.stl, turbine_housing_bot.stl, turbine_wheel.stl]
2014-07-16 Custom Components for PCB Express
2014-07-16 Initial design of Ardweeny control board
    [PControl.sch]
2014-07-18 Latest Schematic and Layout for Ardweeny Driver board
    [ADriver.sch]
2014-07-19 silkscreen, groundplane touchup, bypass capacitors added
2014-07-19 Update README.md
    Added Arduino software prerequisite
2014-07-30 Switchbox diagram added
2014-11-07 added pump files to rotary2
2014-11-07 added names to pump, global high-current activation
2014-11-08 pump testing and global priming and high-power flags
2015-03-29 new turbidometer design
    [turbo.scad]
2015-03-29 box around outside tm/tu sensor
    [turbo.scad]
2015-04-17 Cellstat arduino code added
2015-04-17 Temp/Turbidity sensor and mirror assembly
    [cellstat.scad]
2015-04-20 pump rail code added
2015-04-20 pump dir added
2015-04-29 Camera demo
2015-05-03 outdoor camera support
2015-05-06 levels from USB camera
2015-05-06 erode->dilate profile for USB camera
2015-05-10 talking to pumps
2015-06-30 new autosampler tube holders
    [spair.scad]
2015-06-30 new dc motor valve
2015-07-10 new lean (single device) GUI
2015-07-10 new lean (single device) GUI test image
2015-07-12 popups on the buttons
2015-07-12 new button object with bluetooth
2015-07-14 darkgreen pump status
2015-07-15 pump dialog group test
2015-07-16 pump group fixed
2015-07-27 stack printing on empty image
2015-08-01 new cap/septa for aspirator cellstat
    [cellstatcap.scad]
2015-08-03 autosampler parts
    [newsample.scad]
2015-08-09 little (100mL) lagoon caps
    [lagoon100cap.scad, lagoon100cap.stl]
2015-08-09 tight fitting cap
    [lagoon100cap.scad]
2015-08-10 whole assembly and large bottle caps/septa
    [lagoon250cap.scad, samplemotor.scad]
2015-08-10 crosses added
    [lagoon100cap.scad, lagoon250cap.scad]
2015-08-10 new cellstat cap
    [cellstatcap.scad]
2015-08-21 better error handling, get_codes/2 timeout
    [wifi.ino]
2015-08-23 tightening up the code
2015-08-23 Prolog device/access point data added
2015-08-23 new device enumeration
2015-08-31 logo caps
    [cellstatcaplogo.scad, innatrix_logo.scad, smalllogocap.scad]
2015-09-04 built-in camera (Elapse) must throw away first frame
2015-09-04 frame count and darkness threshold for lumosity added to template
2015-09-06 Added temperature sensor pinouts
2015-09-06 turbidostat.scad added
    [turbidostat.scad]
2015-09-06 avoid sprintf float problem with high/low temp digits.
    [host.ino]
2015-09-07 better error reporting on changed camera IP
2015-09-10 flow calibration roughed in
2015-09-10 infrastruct for in/out flow blocking (incomplete)
2015-09-17 merged host/lagoon valve control
2015-09-29 reverse polarity on led, vNxxxx now sets valve time
    [lagoon2.ino, valves.h]
2015-10-06 frame counter for lux integration
2015-10-21 optical shield on mirror assy
    [turbidostatbar.scad]
2015-10-21 smaller mirror slot for stainless steel mirror
    [turbidostatbar.scad]
2015-10-28 param.h has values for 5 servo positions
2015-10-29 positional valve class
2015-10-30 Lagoon with servo positional valve
2015-10-31 Debian environment stuff
    [launchtaskbar.cfg]
2015-10-31 inflow and outflow valves working
2015-11-16 temperature in tenths not float
2015-12-01 Unsigned long arithmetic broken!
    [drain.ino, drains.h]
